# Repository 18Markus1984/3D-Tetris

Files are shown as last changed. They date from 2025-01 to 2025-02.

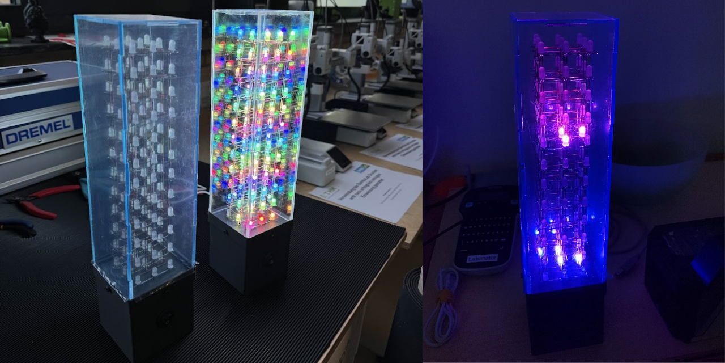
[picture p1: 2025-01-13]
picture_videos/GitHub.png

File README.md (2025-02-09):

# 3D Tetris on a 3x3x12 LED Matrix

Welcome to the 3D Tetris project! This repository documents the creation of a 3x3x12 LED matrix that enables users to play a fully functional 3D Tetris game. The project leverages an ESP32-based development board (ESPduino) with integrated web server functionality for remote control.





## Project Overview

This project was developed as part of the **"Applied Microcontroller Technology"** module and integrates hardware assembly, software programming, and web-based GUI design. Inspired by the game available at [3DTetris.de](https://3dtetris.de/), the system enables interactive gameplay through a wireless web interface.

Key features include:
- A custom-built 3x3x12 RGB LED matrix.
- ESP32 microcontroller for controlling LEDs and hosting a local web server.
- A responsive web interface for gameplay and real-time interactions.
- Open-source software written in C, HTML, CSS, and JavaScript.

---

## Features

### Hardware
- **ESPduino Controller**: Combines the ESP32 Wi-Fi chip with Arduino-compatible GPIO layout.
- **3x3x12 LED Matrix**: Comprised of 108 individually addressable PL9823 RGB LEDs.
- **Custom Housing**: 3D-printed for modularity and ease of assembly.
- **Power Supply**: Powered via USB-C with an integrated on/off switch.

### Software
- **LED Control**: Powered by the FastLED library for efficient matrix management.
- **Game Logic**: Implements Tetris gameplay mechanics including rotation, collision detection, and line clearing.
- **Web Interface**: HTML/CSS-based [GUI](./picture_videos/webserver_gui.png) hosted via an onboard web server, with multi-language support.

### Gameplay
- Control Tetrominoes (Tetris blocks) through the GUI.
- Real-time rendering of blocks on the LED matrix.
- Score tracking and high-score leaderboard.
- Adjustable levels and difficulty scaling.
- High-score table to save and display the top 10 scores.
- Difficulty selection for custom gameplay experiences.

---

## Getting Started  

### Prerequisites  

#### Assembly
- [Circuit](https://github.com/18Markus1984/3D-Tetris/wiki/Soldering-the-Circuit): The LED matrix is powered and controlled through a single GPIO pin of the ESPduino. A 5V USB-C power supply is used for both the matrix and the ESPduino.
- [LED Matrix](https://github.com/18Markus1984/3D-Tetris/wiki/Building-the-LED-Matrix): LEDs are arranged in a 3x3x12 grid and tested individually for functionality. Custom fixtures were used to ensure precision during soldering. 
- [3D printed Case](https://github.com/18Markus1984/3D-Tetris/wiki/Assembling-the-Case): The case, 3D-printed using PLA, features dedicated mounts for the ESPduino, USB ports, and optional counterweights to enhance stability.
- [How the Code Works](https://github.com/18Markus1984/3D-Tetris/wiki/How-the-Code-Works): The ESP32 Tetris game is explained using a flowchart, detailing initialization, web interface, user input processing, game logic, scoring, and game over handling.

#### Software  
- **Arduino IDE**: Download and install the [Arduino IDE](https://www.arduino.cc/en/software).  
- **ESP32 Board Manager**: Add the ESP32 board manager by following [this guide](https://docs.espressif.com/projects/arduino-esp32/en/latest/getting_started.html).  
- **Libraries**: Install the following libraries:  
  - Via Arduino IDE Library Manager:  
    - `FastLED`  
    - `WiFi`  
    - `Preferences`  
  - **ESPForm Library**:  
    - Download the library from the [ESPForm GitHub repository](https://github.com/mobizt/ESPForm).  
    - Extract the downloaded ZIP file.  
    - Copy the extracted folder into the `libraries` directory of your Arduino IDE sketchbook folder.  

### Installation  

1. **Clone the Repository**  
   Open a terminal and run the following command to clone the repository:  
   ```bash  
   git clone https://github.com/18Markus1984/3D-Tetris.git  
   ```  

2. **Open the Project in Arduino IDE**  
   Navigate to the cloned folder and open the `.ino` file in the Arduino IDE.  

3. **Configure the ESP32 Board**  
   - Go to **Tools** > **Board** and select **ESP32 Dev Module**.  
   - Enable **PSRAM** under **Tools** > **PSRAM**.  

4. **Upload the Sketch**  
   - Ensure the correct COM port is selected under **Tools** > **Port**.  
   - Click the **Upload** button to flash the code onto the ESPduino.  

5. **Connect to the ESP32's Wi-Fi Network**  
   - On your computer or mobile device, connect to the Wi-Fi network:  
     - **SSID**: `3D-Tetris`  
     - **Password**: `12345678`  

6. **Access the Web Interface**  
   - Open a web browser and navigate to:  
     - [http://192.168.4.1](http://192.168.4.1)  

You can now enjoy 3D Tetris using the interactive web interface!  

---

## How It Works

### Code Flow Chart
```mermaid
graph TD;
    Start["ESP32 starts"] --> InitWiFi["Initialize WiFi"];
    InitWiFi --> LoadWebPage["Load webpage from html.h"];
    LoadWebPage --> WaitForClient["Wait for client requests"];
    
    WaitForClient -->|Start button pressed| StartGame["Start game"];
    StartGame --> GameLoop["Game loop"];
    
    GameLoop -->|Movement input received| UpdatePosition["Update piece position"];
    UpdatePosition --> GameLoop;
    
    GameLoop -->|Rotation input received| RotatePiece["Rotate piece"];
    RotatePiece --> GameLoop;
    
    GameLoop -->|Piece falls| CheckCollision["Check collision"];
    CheckCollision -->|Collision detected| PlacePiece["Place piece"];
    PlacePiece --> CheckLines["Check for complete lines"];
    CheckLines -->|Lines found| RemoveLines["Remove lines"];
    RemoveLines --> UpdateScore["Update score"];
    UpdateScore --> GameLoop;
    
    CheckLines -->|No lines| GameLoop;
    
    GameLoop -->|Game over| GameOver["Game Over"];
    GameOver --> WaitForClient;
```

### LED Matrix
- **Construction**: LEDs are arranged in a 3x3x12 format, connected using PL9823-compatible drivers.
- **Control**: Each LED is addressed individually using a mapped index for 3D coordinates.

### Web Interface
- **Languages Supported**: English, German, French, Spanish, Italian.
- **Functions**:
  - Rotate blocks around X, Y, Z axes.
  - Shift blocks along the XY-plane.
  - Drop blocks into place.
- **Additional Features**:
  - Live preview of the next Tetromino.
  - Display of current score and level.
  - **High-Score Table**: Saves and displays the top 10 scores along with player names. Extra entries are shown but not stored persistently.
  - **Difficulty Selection**: Choose between multiple difficulty levels to adjust the gameplay experience.

---

## Results

The project met its primary objectives, showcasing:
1. A functional 3D Tetris game on a custom LED matrix.
2. An intuitive and accessible web-based control interface.
3. High scalability for future enhancements, including battery power and improved stability.

---

## Future Improvements
- Reduce input latency for smoother gameplay.
- Enhance matrix stability to minimize movement during transport.
- Add battery support for portability.
- Optimize collision detection and rotation algorithms to avoid edge-case errors.

---

## Acknowledgments

This project was developed by Marvin Heins, Markus Schmidt, and Leonard Holz-Diehl. Special thanks to the open-source community and the developers of the FastLED library.

---

## License

This project is licensed under the GNU General Public License v3.0. See the `LICENSE` file for more details.

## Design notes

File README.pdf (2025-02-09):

README.md | 2025-02-09

# 3D Tetris on a 3x3x12 LED Matrix

Welcome to the 3D Tetris project! This repository documents the creation of a 3x3x12 LED matrix that enables users to play a fully functional 3D Tetris game. The project leverages an ESP32-based development board (ESPduino) with integrated web server functionality for remote control.

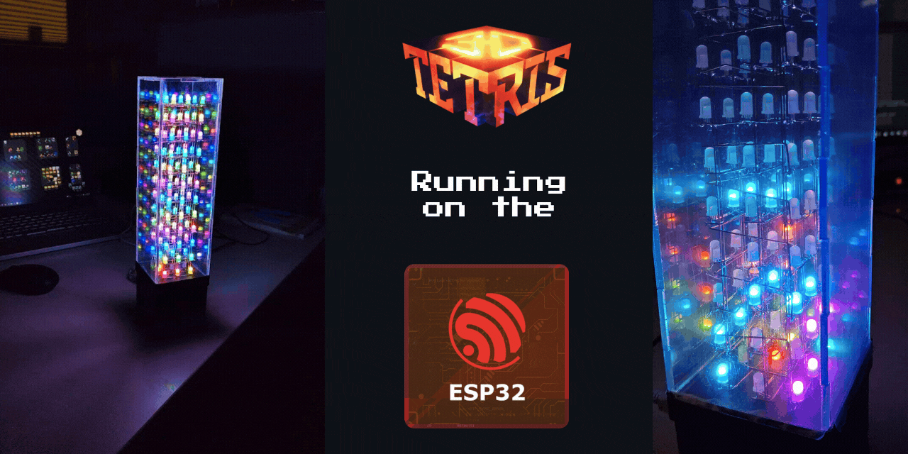
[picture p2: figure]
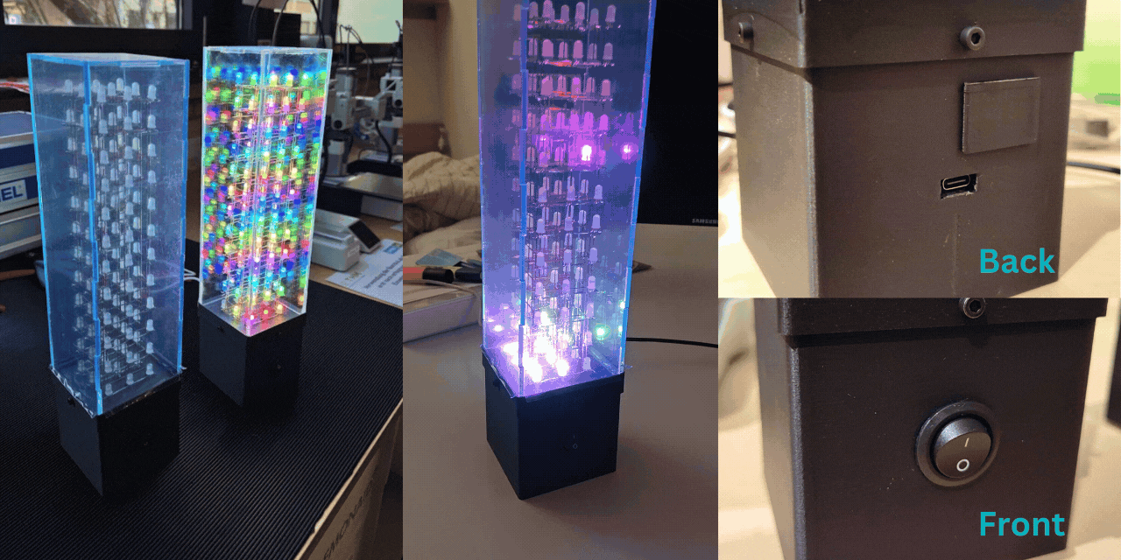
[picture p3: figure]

## Project Overview

This project was developed as part of the "Applied Microcontroller Technology" module and integrates hardware assembly, software programming, and web-based GUI design. Inspired by the game available at 3DTetris.de, the system enables interactive gameplay through a wireless web interface.

Key features include:

A custom-built 3x3x12 RGB LED matrix.
ESP32 microcontroller for controlling LEDs and hosting a local web server. A responsive web interface for gameplay and real-time interactions. Open-source software written in C, HTML, CSS, and JavaScript.

## Features

Hardware

ESPduino Controller: Combines the ESP32 Wi-Fi chip with Arduino-compatible GPIO layout. 3x3x12 LED Matrix: Comprised of 108 individually addressable PL9823 RGB LEDs.
Custom Housing: 3D-printed for modularity and ease of assembly.
Power Supply: Powered via USB-C with an integrated on/off switch.
Software

LED Control: Powered by the FastLED library for efficient matrix management.
Game Logic: Implements Tetris gameplay mechanics including rotation, collision detection, and line clearing.
Web Interface: HTML/CSS-based GUI hosted via an onboard web server, with multi-language support.
Gameplay

Control Tetrominoes (Tetris blocks) through the GUI.
Real-time rendering of blocks on the LED matrix. Score tracking and high-score leaderboard. Adjustable levels and difficulty scaling.
High-score table to save and display the top 10 scores. Difficulty selection for custom gameplay experiences.

## Getting Started

Prerequisites

Assembly

Circuit: (https://github.com/18Markus1984/3D-Tetris/wiki/Soldering-the-Circuit) The LED matrix is powered and controlled through a single GPIO pin of the ESPduino. A 5V USB-C power supply is used for both the matrix and the ESPduino.
LED Matrix: (https://github.com/18Markus1984/3D-Tetris/wiki/Building-the-LED-Matrix) LEDs are arranged in a 3x3x12 grid and tested individually for functionality. Custom fixtures were used to ensure precision during soldering.
3D printed Case: (https://github.com/18Markus1984/3D-Tetris/wiki/Assembling-the-Case) The case, 3D-printed using PLA, features dedicated mounts for the ESPduino, USB ports, and optional counterweights to enhance stability.
How the Code Works: (https://github.com/18Markus1984/3D-Tetris/wiki/Flowchart-Walkthrough:-How-the-Code-Works) The ESP32 Tetris game is explained using a flowchart, detailing initialization, web interface, user input processing, game logic, scoring, and game over handling.

Software

Arduino IDE: Download and install the Arduino IDE. (https://www.arduino.cc/en/software)
ESP32 Board Manager: Add the ESP32 board manager by following this guide. (https://docs.espressif.com/projects/arduino-esp32/en/latest/getting_started.html) Libraries: Install the following libraries:
Via Arduino IDE Library Manager:
FastLED
WiFi
Preferences
ESPForm Library:
Download the library from the ESPForm GitHub repository. (https://github.com/mobizt/ESPForm)
Extract the downloaded ZIP file.
Copy the extracted folder into the libraries directory of your Arduino IDE sketchbook folder.
Installation
1. Clone the Repository
Open a terminal and run the following command to clone the repository:
2. Open the Project in Arduino IDE
Navigate to the cloned folder and open the .ino file in the Arduino IDE.
3. Configure the ESP32 Board

Go to Tools > Board and select ESP32 Dev Module.
Enable PSRAM under Tools > PSRAM.
4. Upload the Sketch

Ensure the correct COM port is selected under Tools > Port. Click the Upload button to flash the code onto the ESPduino.

5. Connect to the ESP32's Wi-Fi Network

On your computer or mobile device, connect to the Wi-Fi network: SSID: 3D-Tetris
Password: 12345678
6. Access the Web Interface

Open a web browser and navigate to: http://192.168.4.1

You can now enjoy 3D Tetris using the interactive web interface!

## How It Works

Code Flow Chart

graph TD;
Start["ESP32 starts"] --> InitWiFi["Initialize WiFi"];
InitWiFi --> LoadWebPage["Load webpage from html.h"]; LoadWebPage --> WaitForClient["Wait for client requests"];

WaitForClient -->|Start button pressed| StartGame["Start game"];
StartGame --> GameLoop["Game loop"];

GameLoop -->|Movement input received| UpdatePosition["Update piece position"]; UpdatePosition --> GameLoop;

GameLoop -->|Rotation input received| RotatePiece["Rotate piece"]; RotatePiece --> GameLoop;

GameLoop -->|Piece falls| CheckCollision["Check collision"]; CheckCollision -->|Collision detected| PlacePiece["Place piece"]; PlacePiece --> CheckLines["Check for complete lines"]; CheckLines -->|Lines found| RemoveLines["Remove lines"]; RemoveLines --> UpdateScore["Update score"];
UpdateScore --> GameLoop;

CheckLines -->|No lines| GameLoop;

GameLoop -->|Game over| GameOver["Game Over"]; GameOver --> WaitForClient;

LED Matrix

Construction: LEDs are arranged in a 3x3x12 format, connected using PL9823-compatible drivers. Control: Each LED is addressed individually using a mapped index for 3D coordinates.
Web Interface

Languages Supported: English, German, French, Spanish, Italian.
Functions:
Rotate blocks around X, Y, Z axes.
Shift blocks along the XY-plane.
Drop blocks into place.
Additional Features:
Live preview of the next Tetromino.
Display of current score and level.
High-Score Table: Saves and displays the top 10 scores along with player names. Extra entries are shown but not stored persistently.
Difficulty Selection: Choose between multiple difficulty levels to adjust the gameplay experience.

## Results

The project met its primary objectives, showcasing:

1. A functional 3D Tetris game on a custom LED matrix.
2. An intuitive and accessible web-based control interface.
3. High scalability for future enhancements, including battery power and improved stability.

## Future Improvements

Reduce input latency for smoother gameplay.
Enhance matrix stability to minimize movement during transport.
Add battery support for portability.
Optimize collision detection and rotation algorithms to avoid edge-case errors.

## Acknowledgments

This project was developed by Marvin Heins, Markus Schmidt, and Leonard Holz-Diehl. Special thanks to the open-source community and the developers of the FastLED library.

## License

This project is licensed under the GNU General Public License v3.0. See the LICENSE file for more details.

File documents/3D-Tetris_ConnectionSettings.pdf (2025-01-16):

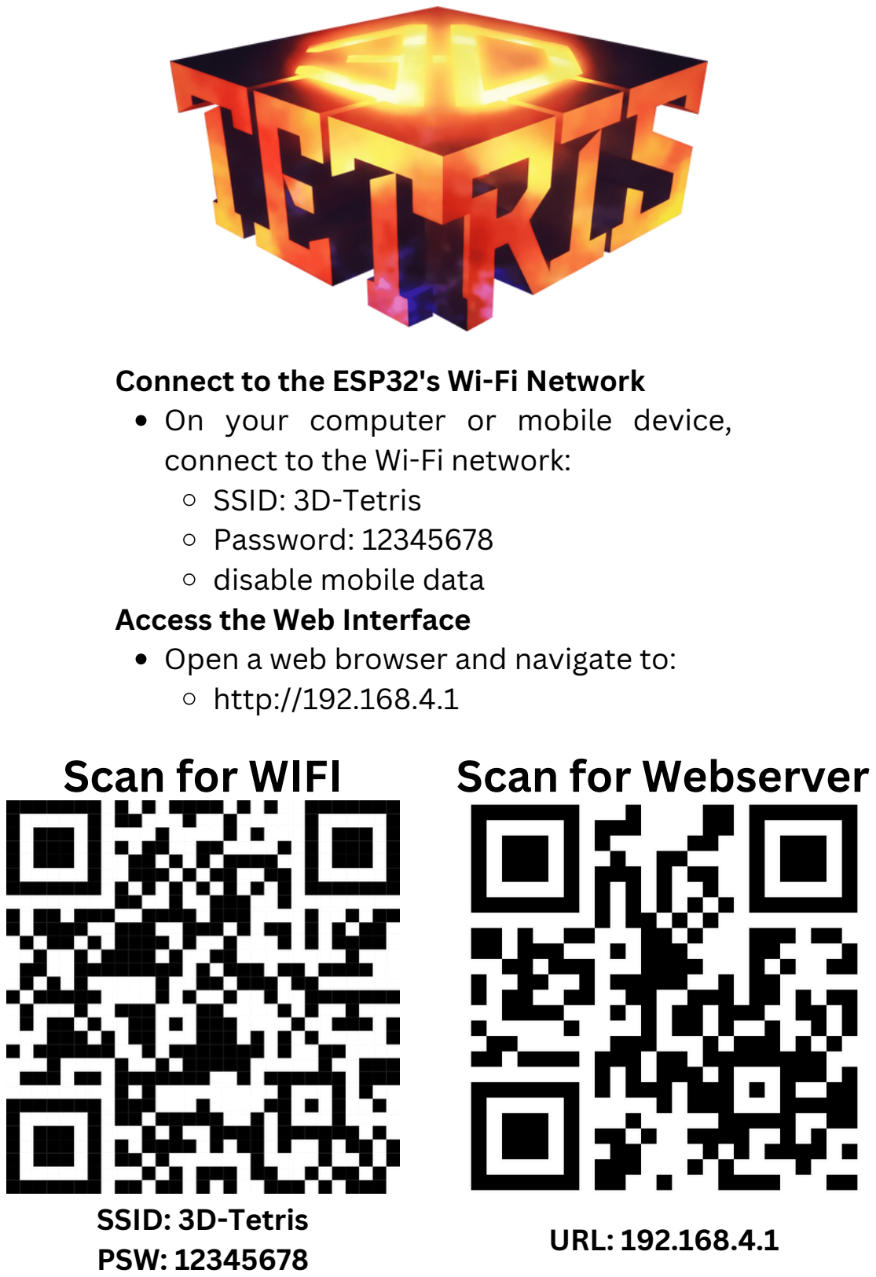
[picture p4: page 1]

## Scan for WIFI Scan for Webserver

Connect to the ESP32's Wi-Fi Network
On your computer or mobile device, connect to the Wi-Fi network:
SSID: 3D-Tetris
Password: 12345678
disable mobile data
Access the Web Interface
Open a web browser and navigate to: http://192.168.4.1

SSID: 3D-Tetris
PSW: 12345678

URL: 192.168.4.1

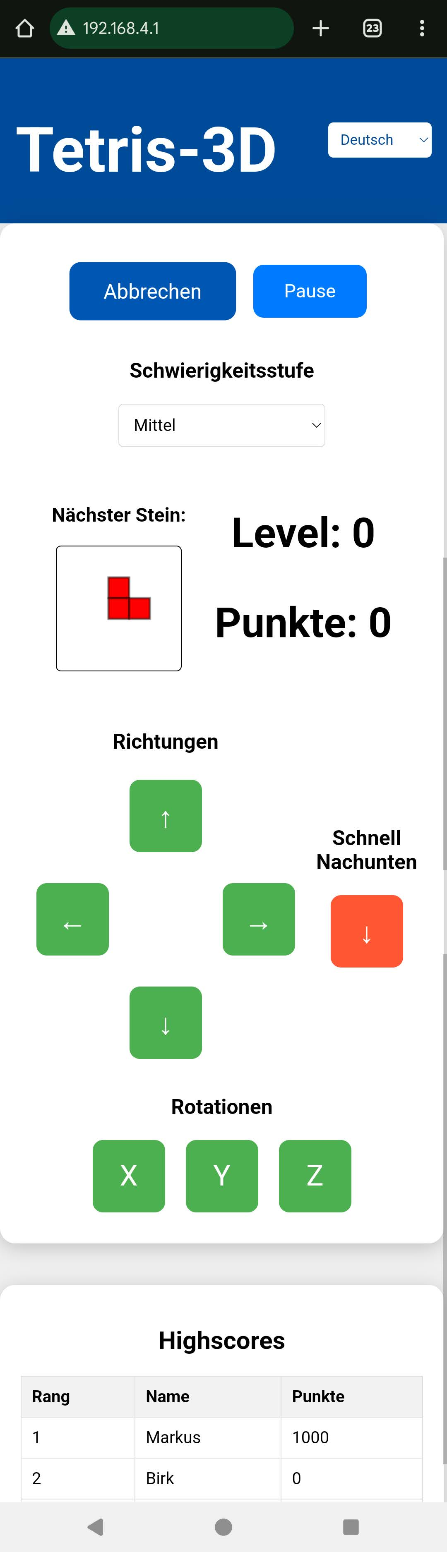
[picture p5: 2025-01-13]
picture_videos/webserver_gui.png

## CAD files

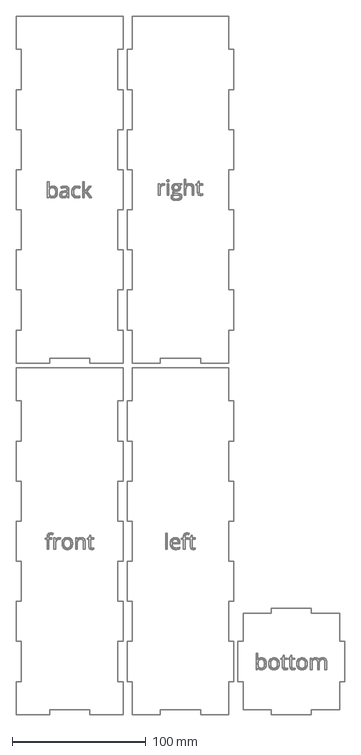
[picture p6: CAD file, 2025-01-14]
3D-Model/Laser_Milling/plexiglas_cutting.dxf
246.0 x 523.0 mm

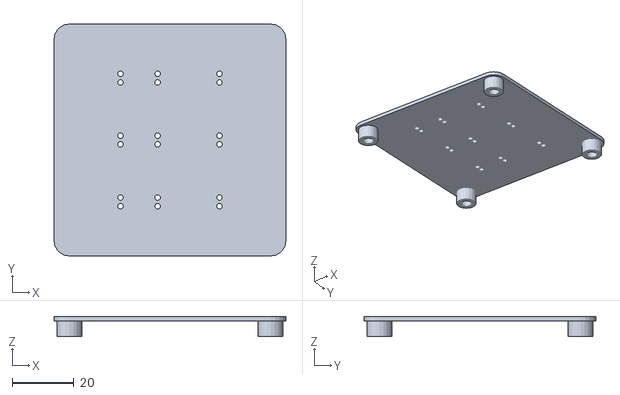
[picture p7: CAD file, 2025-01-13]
3D-Model/STLs/case/LED_Cube_Halter_V2.stl
75.0 x 75.0 x 6.50

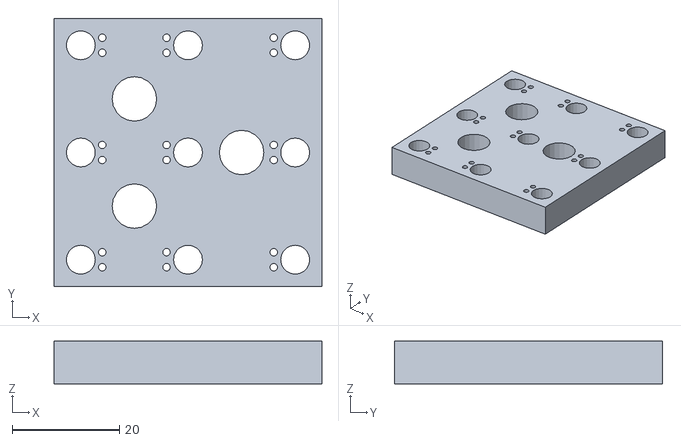
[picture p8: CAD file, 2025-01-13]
3D-Model/STLs/parts_to_solder_matrix/Guide_LED_Cube_V5.stl
50.0 x 50.0 x 8.00

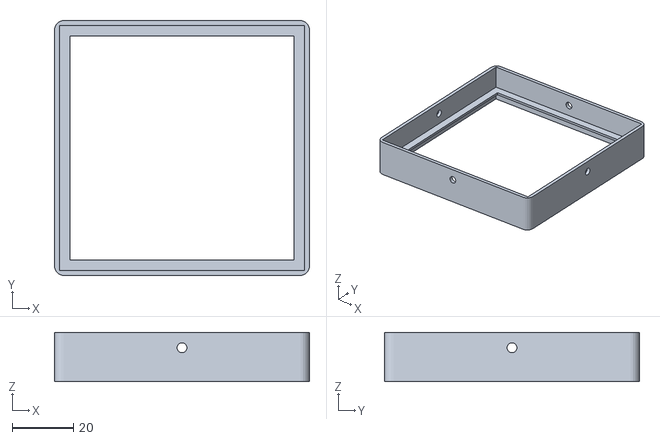
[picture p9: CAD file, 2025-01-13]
3D-Model/STLs/case/Aufsatz_Plexi_Schraube.stl
83.0 x 83.0 x 16.0

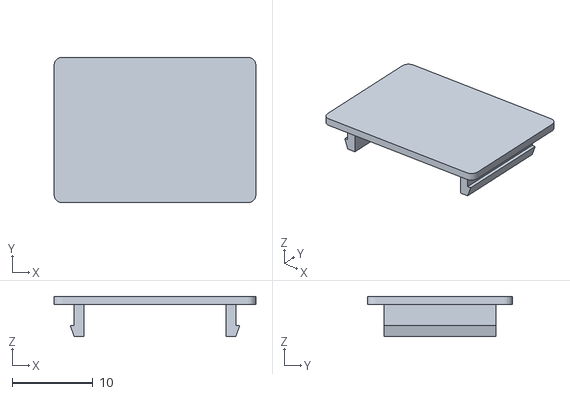
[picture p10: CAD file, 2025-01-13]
3D-Model/STLs/case/Abdeckung05.stl
25.0 x 18.0 x 5.00

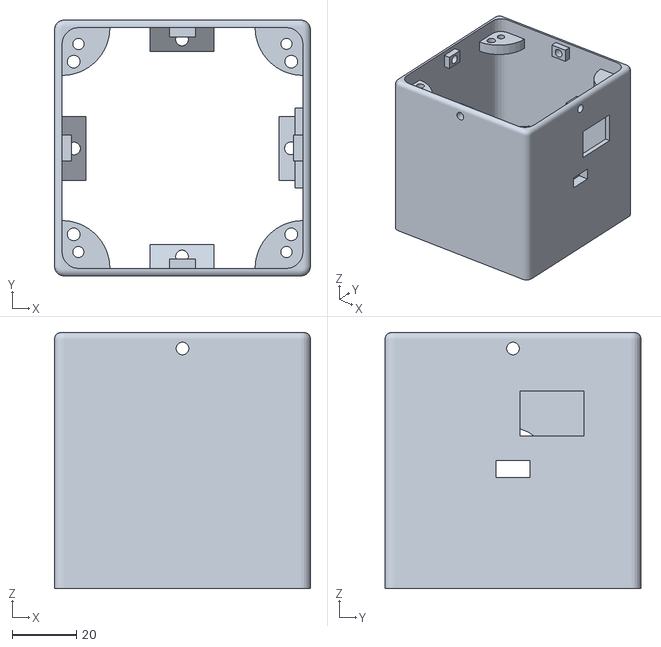
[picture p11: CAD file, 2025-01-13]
3D-Model/STLs/case/Gehauese_LED_Cube_plex.stl
80.0 x 80.0 x 80.0

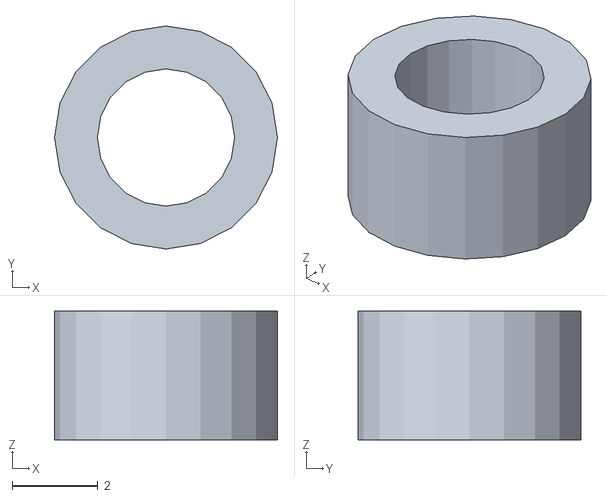
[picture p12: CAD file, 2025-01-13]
3D-Model/STLs/case/Spacer.stl
5.20 x 5.20 x 3.00

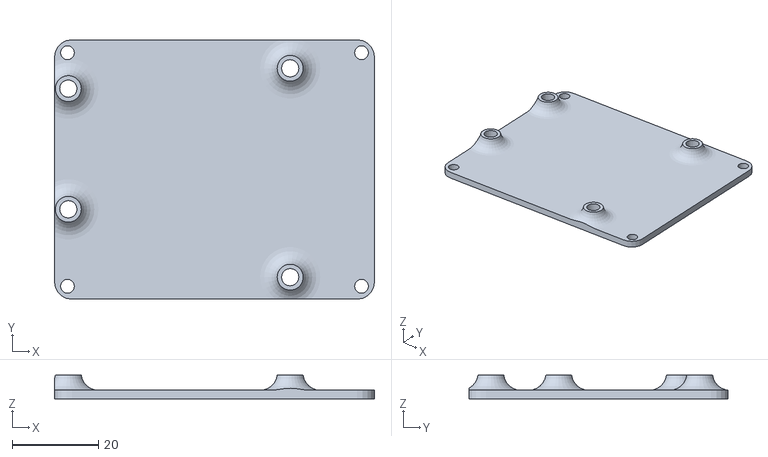
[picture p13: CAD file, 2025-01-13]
3D-Model/STLs/case/Halter_ESPduino.stl
74.0 x 60.0 x 5.50

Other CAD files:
3D-Model/NX/Abdeckung.prt
3D-Model/NX/Aufsatz_Plexi.prt
3D-Model/NX/Baugruppe_LED_Cube.prt
3D-Model/NX/Gehauese_LED_Cube.prt
3D-Model/NX/Halter_ESPduino.prt
3D-Model/NX/LED_Cube_Halter.prt
3D-Model/NX/Spacer.prt

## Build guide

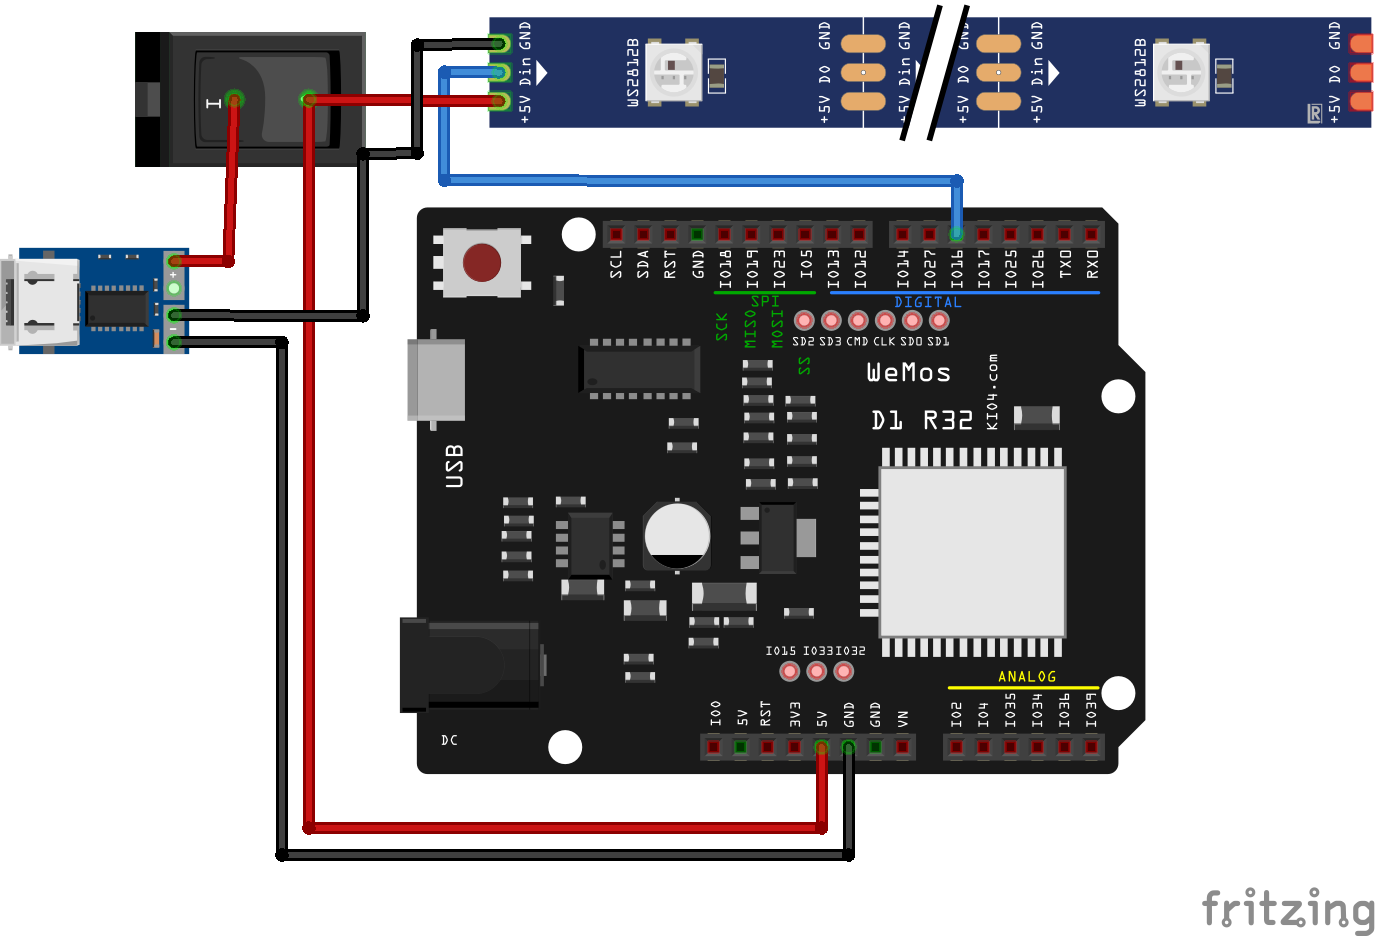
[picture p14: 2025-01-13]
picture_videos/wiring_diagram.png

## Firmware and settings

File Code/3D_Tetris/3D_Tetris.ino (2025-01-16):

//libraries used 
#include <FastLED.h>
#include <WiFi.h> //ESP32
#include <ESPForm.h>
#include <Preferences.h>

//Split into different files for better legibility 
#include "html.h"
String configFileName = "/wifi.json";

//The Wifi-credentials for logging in 
String apSSID = "3D-Tetris";
String apPSW = "12345678";
unsigned long serverTimeout = 2 * 60 * 1000;


const int X_DIM = 3;  // dimensin in X-direction
const int Y_DIM = 3;  // dimension in Y-direction
const int Z_DIM = 12;  // Adjustable dimension in Z-direction (testet for 10 and 12)

//LED Settings
#define LED_PIN 16
#define NUM_LEDS 108     // Number of LEDs
#define MAX_X 3          // Dimension X (3 layers)
#define MAX_Y 3          // Dimension Y (3 lines)
#define MAX_Z 12         // Dimension Z (12 columns)

//Idle Animation
#define TEMPERATURE_1 Tungsten100W
#define TEMPERATURE_2 OvercastSky
#define BRIGHTNESS  80

// How many seconds to show each temperature before switching
#define DISPLAYTIME 20

// How many seconds to show black between switches
#define BLACKTIME   1

// FastLED-Array  
CRGB leds[NUM_LEDS];

//Eeproom-adresses
Preferences preferences;

//Storage for the 3D-Matrix digital twin (with the variable dimensions)
int matrix[X_DIM][Y_DIM][Z_DIM]; 

//Color Options
byte color[25][3] = {{255,0,0},{255,64,0},{255,128,0},{255,191,0},{255,255,0},{191,255,0},{128,255,0},{64,255,0},{0,255,0},{0,255,64},{0,255,128},{0,255,191},{0,255,255},{0,191,255},
{0,128,255},{0,64,255},{0,0,255},{64,0,255},{128,0,255},{191,0,255},{255,0,255},{255,0,191},{255,0,128},{255,0,64},{255,0,0}};  //Array with the different color-values would be better to do this with a function
int row = 0;  //variable, that shows which color is selected 

//Struct for Tetrominos with extended points
struct Tetromino {
    int points[5][3];  // The 5 points in the format of {x, y, z}; non used values are set to -3
    int xPos;         // X-Position of the  Tetrominos
    int yPos;         // Y-Position of the Tetrominos
    int colorIndex;    // Color of the Tetrominos (Index in color-Array)
};

// Tetrominos with 5 points (non used points set to -3)
Tetromino tetrominos[] = {
    //Easy mode:
    // Point-Tetromino - 0
    {
        {{1, 1, 1}, {-3, -3, -3}, {-3, -3, -3}, {-3, -3, -3}, {-3, -3, -3}}, 
        0,0,0 // Color
    },
    // I-Tetromino - 1
    {
        {{0, 1, 1}, {1, 1, 1}, {2, 1, 1}, {-3, -3, -3}, {-3, -3, -3}},
        0,0,0  // Color
    },
    // Small-I-Tetromino - 2
    {
        {{0, 1, 1}, {1, 1, 1}, {-3, -3, -3}, {-3, -3, -3}, {-3, -3, -3}}, 
        0,0,0  // Color
    },
    //middle:
    // L-Tetromino - 3
    {
        {{1, 0, 1}, {1, 1, 1}, {1, 2, 1}, {2, 2, 1}, {-3, -3, -3}}, 
        0,0,0  // Color
    },
    // T-Tetromino - 4
    {
        {{1, 0, 1}, {0, 1, 1}, {1, 1, 1}, {2, 1, 1}, {-3, -3, -3}}, 
        0,0,0  // color
    },
    // S-Tetromino - 5
    {
        {{0, 1, 1}, {1, 0, 1}, {1, 1, 1}, {2, 0, 1}, {-3, -3, -3}}, 
        0,0,0  // Color
    },
    // o-Tetromino - 6
    {
        {{0, 0, 1}, {0, 1, 1}, {1, 0, 1}, {1, 1, 1}, {-3, -3, -3}}, 
        0,0,0  // Color
    },
    // Small-L-Tetromino - 7
    {
        {{0, 1, 1}, {1, 1, 1}, {1, 2, 1}, {-3, -3, -3},{-3, -3, -3}}, 
        0,0,0  // color
    },
    //Expert:
    // Star-Tetromino - 8
    {
        {{0, 1, 1}, {1, 0, 1}, {1, 1, 1},  {2, 1, 1}, {1, 2, 1}}, 
        0,0,0  // Color
    },
    // Big-S-Tetromino - 9
    {
        {{0, 0, 1}, {0, 1, 1}, {1, 1, 1},  {2, 1, 1}, {2, 2, 1}}, 
        0,0,0  // Color
    },
    // Big-T-Tetromino - 10
    {
        {{0, 1, 1}, {1, 1, 1}, {2, 0, 1}, {2, 1, 1}, {2, 2, 1}}, 
        0,0,0  // Color
    },
    // Handy-Tetromino - 11
    {
        {{0, 1, 1}, {1, 1, 1}, {1, 0, 1},{2, 1, 1}, {2, 0, 1}}, 
        0,0,0  // Color
    },
    // Big-U-Tetromino - 12
    {
        {{0, 0, 1}, {0, 1, 1}, {1, 1, 1}, {2, 1, 1}, {2, 0, 1}}, 
        0,0,0  // Color
    },
    // Big-L-Tetromino - 13
    {
        {{0, 0, 1}, {0, 1, 1}, {0, 2, 1}, {1, 2, 1}, {2, 2, 1}}, 
        0,0,0  // Color
    },
    // L with dot -Tetromino - 14
    {
        {{1, 0, 1}, {1, 1, 1}, {1, 2, 1}, {2, 2, 1}, {0, 1, 1}}, 
        0,0,0  // Color
    },
    // stair-Tetromino - 15
    {
        {{0, 0, 1}, {0, 1, 1}, {1, 1, 1}, {1, 2, 1}, {2, 2, 1}}, 
        0,0,0  // Color
    },

    //3D Terominos:
    // 3*1 with corner -Tetromino - 16
    {
        {{0, 1, 1}, {1, 1, 1}, {2, 1, 1}, {0, 0, 0}, {1, 0, 0}}, 
        0,0,0  // Farbe
    },
    // L with dot -Tetromino - 17
    {
        {{1, 0, 1}, {1, 1, 1}, {1, 2, 1}, {2, 2, 1}, {1, 1, 0}}, 
        0,0,0  // Farbe
    },
    // T with dot -Tetromino - 18
    {
        {{1, 0, 1}, {0, 1, 1}, {1, 1, 1}, {2, 1, 1}, {1, 1, 0}}, 
        0,0,0  // Farbe
    },
    // S with dot -Tetromino - 20
    {
        {{0, 1, 1}, {1, 0, 1}, {1, 1, 1}, {2, 0, 1}, {1, 1, 0}}, 
        0,0,0  // Farbe
    },
    // o with dot -Tetromino - 21
    {
        {{0, 0, 1}, {0, 1, 1}, {1, 0, 1}, {1, 1, 1}, {1, 1, 0}}, 
        0,0,0  // Farbe
    },
    // Small-KoordinatenSystem-Tetromino - 22
    {
        {{0, 1, 1}, {1, 1, 1}, {1, 2, 1},{1, 1, 0}, {-3, -3, -3}}, 
        0,0,0  // Farbe
    }
};

//Tetris realted Variables:
Tetromino currentTetromino;   // The active Tetromino
int nextTetrominoIndex = 0;   // The next Tetromino block as index of the Arrays
int currentZ = 0;             // Latest Z-Position of the falling Tetrominos
bool gameRunning = false;     // Variable to check if the game is running right now 
int gameDelay = 1000;         // variable to track the time of the now running action. Examples: block is falling or collision of blocks
int score = 0;                // variable to store the score of the running game
int levelScore = 0;           // variable that shows the level in which the user is. the level inceases every 10th layer they cleared
String playerData = "";       // string which buffers the highscore data
int difficulty = 0;           // variable to set the difficulty of the game
bool changeScore = false;     // toggle to signal that the new score has to be saved
int ElementCounter = 0;
ESPFormClass::HTMLElementItem ElementTrigger;   // set a Element for the Element press/or value change interrupts
ESPFormClass::HTMLElementItem PreviousElementTrigger; 
String elementButton = "";

//regular Arduino functions
void setup();
void loop();

//3D-Tetris related functions
void idleAnimtation();                                                                 // function that shows an animation while no game is running
void gameOver();                                                                       // function to reset all values after gameOver
void saveData(String highscoreString);                                                 // function that saves the Highscore values on the Eproom of the Esp
void splitHighscores(String input, String names[], int scores[], int maxEntries);      // function to split the input string into different HighScore values
void clearMatrix();                                                                    // funciton to clear the matrix
int XYZ_to_index(int x, int y, int z);                                                 // function to calculate the LED-Index based on 3D-coordinates
void updateLEDs();                                                                     // function to refresh the LEDs based on the matrix
void renderTetromino(Tetromino &tetromino, int z, bool clear);                         // function to draw the position of the tetromino in the matrix temporary
void placeTetromino(Tetromino &tetromino, int z);                                      // function to put the tetromino in the matrix
bool moveTetrominoDown(Tetromino &tetromino);                                          // funciton to move the tetromino down
bool canPlaceTetromino(Tetromino &tetromino, int z);                                   // function to check the placement of the tetromino (collison check)
void updateAndDisplayMatrix();                                                         // function to display the game matrix in the serial monitor 
void spawnNewTetromino();                                                              // function to chose a random new Tetromino
int spawnRelativeToDiff();                                                             // function that returns a random new Tetromino relative to the selected difficulti
void clearFullLevelAndShiftDown(int level);                                            // function that removes the layer and shifts every upper layer on layer lower
void checkFullLevel();                                                                 // function that checkes every layer if it is filled with blocks

//3D-Tetris movment and rotation related functions
void moveTetromino(Tetromino &tetromino, int dx, int dy, int dz);   // General movement function that moves Tetromenio in x, y or z direction depending on the input 
void fallDown(Tetromino &tetromino);                                // function that lets the Tetromino fall down until it finds a collision with a block or the ground
void rotateTetromino(Tetromino &tetromino, char axis);              // General rotation function, which is responsible for rotation in every individual funciton
bool AdjustPosition(Tetromino &tetromino, int &currentZ);           // function to find a postion if the Tetromino rotates out of the gameMatrix

//wifi and webserver realted functions
bool startWiFi();                                                         //starts the Wifi protocol
void setupESPForm();                                                      //Initialised all the EventListener for the comminication between Esp and HTML
void formElementEventCallback(ESPFormClass::HTMLElementItem element);     //function that gets called if any of the EventListener get triggered. Used to get the different button presses and value changes
void checkForGameControllElements(ESPFormClass::HTMLElementItem element); //function that calls all calls the differnt functions for every button
void serverTimeoutCallback();                                             //If server timeout (no client connected within specific time)


void setup() {
  Serial.begin(115200);

  WiFi.softAPdisconnect(true);
  WiFi.disconnect(true);
  WiFi.persistent(false);

  if (!startWiFi()) {
    setupESPForm();
    Serial.println("MAIN:  Start server");
    ESPForm.startServer();
  }
  
  FastLED.addLeds<WS2812, LED_PIN, GRB>(leds, NUM_LEDS);

  preferences.begin("myScore", false);
  playerData = preferences.getString("score");
  Serial.println(playerData);
  clearMatrix();        // initiate the matrix
  updateLEDs();
}

void loop() {
  if(ESPForm.getClientCount() > 0) {
    ESPFormClass::HTMLElementItem element = ESPForm.getElementEventConfigItem("gameScores");
    String pufferplayer = element.value; 
    if(pufferplayer == "" || pufferplayer == "null" && playerData != ""){
      ESPForm.setElementContent("gameScores", playerData);
    }
  }
  // Show the matrix in the serial monitor (for debugging)
  //updateAndDisplayMatrix();
  if(gameRunning){
    static unsigned long lastUpdateTime = 0; 
    unsigned long currentTime = millis();
  
    // Check if gameDelay time have passed
    if (currentTime - lastUpdateTime >= gameDelay) {
      lastUpdateTime = currentTime;
      // Try to move the Tetromino down
      if (!moveTetrominoDown(currentTetromino)) {
        // Movement failed -> Spawn new Tetromino
        spawnNewTetromino();
      }
    }
  }
  else {
    idleAnimtation();
  }
  Serial.println(elementButton);
  if(elementButton != "") {
    checkForGameControllElements(elementButton);
    elementButton = "";
  }
}

// function that shows an animation while no game is running
void idleAnimtation(){
  // draw a generic, no-name rainbow
  static uint8_t starthue = 0;
  fill_rainbow( leds + 5, NUM_LEDS - 5, --starthue, 20);

  // Choose which 'color temperature' profile to enable.
  uint8_t secs = (millis() / 1000) % (DISPLAYTIME * 2);
  if( secs < DISPLAYTIME) {
    FastLED.setTemperature( TEMPERATURE_1 ); // first temperature
    leds[0] = TEMPERATURE_1; // show indicator pixel
  } else {
    FastLED.setTemperature( TEMPERATURE_2 ); // second temperature
    leds[0] = TEMPERATURE_2; // show indicator pixel
  }

  // Black out the LEDs for a few seconds between color changes
  // to let the eyes and brains adjust
  if( (secs % DISPLAYTIME) < BLACKTIME) {
    memset8( leds, 0, NUM_LEDS * sizeof(CRGB));
  }
  FastLED.show();
  FastLED.delay(8);
}

// function to reset all values after gameOver
void gameOver(){
  gameRunning = false;
  Serial.println("Game Over!");
  ESPForm.setElementContent("gameOverInput", "GameOver");
  clearMatrix();
  updateLEDs();
}

// function that saves the Highscore values on the Eproom of the Esp
void saveData(String highscoreString){
  Serial.println("SaveData");
  Serial.println(highscoreString);
  int maxEntries = 10; // Max amout of stored entries
  int count = 0;
  String names[maxEntries];
  int scores[maxEntries];
  
  //Call the function
  splitHighscores(highscoreString, names, scores, maxEntries);
  String scoreData = "";
  for (int i = 0; i < maxEntries; i++) {
    if (names[i] != "") { // check if the name is valid
      Serial.print("Name: ");
      Serial.print(names[i]);
      Serial.print(", Score: ");
      Serial.println(scores[i]);
      scoreData+= names[i]+","+scores[i]+";";
    }
  }
  preferences.putString("score",scoreData);
  playerData = scoreData;
}

// function to split the input string into different HighScore values
void splitHighscores(String input, String names[], int scores[], int maxEntries) {
  int entryIndex = 0;
  while (input.length() > 0 && entryIndex < maxEntries) {
    int delimiterPos = input.indexOf(';');
    String entry;
    if (delimiterPos != -1) {
      entry = input.substring(0, delimiterPos);
      input = input.substring(delimiterPos + 1);
    } else {
      entry = input;
      input = "";
    }

    int commaPos = entry.indexOf(',');
    if (commaPos != -1) {
      names[entryIndex] = entry.substring(0, commaPos);
      scores[entryIndex] = entry.substring(commaPos + 1).toInt();
      entryIndex++;
    }
  }
}

// funciton to clear the matrix
void clearMatrix() {
  Serial.println("Clear-Matrix");
  for (int z = 0; z < Z_DIM; z++) {
    for (int y = 0; y < Y_DIM; y++) {
      for (int x = 0; x < X_DIM; x++) {
        matrix[x][y][z] = 0; // Initiate matrix with zero
      }
    }
  }
}

// function to calculate the LED-Index based on 3D-coordinates
int XYZ_to_index(int x, int y, int z) {
  int reverseZ = MAX_Z - 1 - z; // invert z-direction(from top to bottom)
  return (reverseZ * MAX_X * MAX_Y) + (y * MAX_X) + x;
}

// function to refresh the LEDs based on the matrix
void updateLEDs() {
  for (int x = 0; x < MAX_X; x++) {
    for (int y = 0; y < MAX_Y; y++) {
      for (int z = 0; z < MAX_Z; z++) {
        int index = XYZ_to_index(x, y, z);
        if (index < NUM_LEDS) { // check: Index in range
          if (matrix[x][y][z] > 0 && matrix[x][y][z] <= 25) {
            leds[index].setRGB(color[matrix[x][y][z]][0],color[matrix[x][y][z]][1],color[matrix[x][y][z]][2]); // Stone active: colored
          } else {
            leds[index] = CRGB::Black; // stone deactivated: LED off
          }
        }
      }
    }
  }
  FastLED.show();
}

// function to draw the position of the tetromino in the matrix temporary
void renderTetromino(Tetromino &tetromino, int z, bool clear = false) {
    for (int i = 0; i < 5; i++) {
        //Check if the point is vaild (ignore -3)
        if (tetromino.points[i][0] != -3) {
            int nx = tetromino.xPos + tetromino.points[i][0];
            int ny = tetromino.yPos + tetromino.points[i][1];
            int nz = z + tetromino.points[i][2];

            //Check if the point is in the boundaries of the matrix 
            if (nx >= 0 && nx < X_DIM && ny >= 0 && ny < Y_DIM && nz >= 0 && nz < Z_DIM) {
                matrix[nx][ny][nz] = clear ? 0 : tetromino.colorIndex;
            }
        }
    }
}

// function to put the tetromino in the matrix
void placeTetromino(Tetromino &tetromino, int z) {
    for (int i = 0; i < 5; i++) {
        //Check if the point is vaild (ignore -3)
        if (tetromino.points[i][0] != -3) {
            int nx = tetromino.xPos + tetromino.points[i][0];
            int ny = tetromino.yPos + tetromino.points[i][1];
            int nz = z + tetromino.points[i][2];

            //Set the point in the matrix if it is valid
            if (nx >= 0 && nx < X_DIM && ny >= 0 && ny < Y_DIM && nz >= 0 && nz < Z_DIM) { 
                matrix[nx][ny][nz] = tetromino.colorIndex;
            }
        }
    }
    // check and delete the complet layer 
    checkFullLevel();
}

//funciton to move the tetromino down
bool moveTetrominoDown(Tetromino &tetromino) {
    // Delete the old position in the current layer (currentZ)
    renderTetromino(tetromino, currentZ-1, true);
    renderTetromino(tetromino, currentZ, true);

    //Check if the tetrominocan be placed in the next layer
    if (canPlaceTetromino(tetromino, currentZ + 1)) {
        //Go down one layer
        currentZ++;
        // Draw the tetromino in the new z-layer
        renderTetromino(tetromino, currentZ);
        updateLEDs();
        return true;
    } else {
        // Place it if no more movment is possible
        Serial.println("Collision detected - Placement of block.");
        placeTetromino(tetromino, currentZ);
        return false;
    }
}

//Function to check the placement of the tetromino (collison check)
bool canPlaceTetromino(Tetromino &tetromino, int z) {
    for (int i = 0; i < 5; i++) {
        // Check if the point is valid (ignore -3)
        if (tetromino.points[i][0] != -3) {
            int nx = tetromino.xPos + tetromino.points[i][0];
            int ny = tetromino.yPos + tetromino.points[i][1];
            int nz = z + tetromino.points[i][2];

            // Debugging-output
            Serial.print("Check block of: (");
            Serial.print(nx);
            Serial.print(", ");
            Serial.print(ny);
            Serial.print(", ");
            Serial.print(nz);
            Serial.println(")");

            //Check if the position is outside of the matrix or collides
            if (nx < 0 || nx >= X_DIM || ny < 0 || ny >= Y_DIM || nz < 0 || nz >= Z_DIM || matrix[nx][ny][nz] != 0) {
                Serial.println("Block outside the matrix boundaries!");
                return false; // Collison detected
            }
        }
    }
    return true; // No collison, placment is empty
}

// Method to display matrix
void updateAndDisplayMatrix() {
  Serial.println("Current state of the 3D-Matrix:");
  for (int z = 0; z < Z_DIM; z++) {
    Serial.print("Layer ");
    Serial.print(z);
    Serial.println(":");
    for (int y = 0; y < Y_DIM; y++) {
      for (int x = 0; x < X_DIM; x++) {
        Serial.print(matrix[x][y][z]);
        Serial.print("\t");
      }
      Serial.println(); // New line for the next row
    }
    Serial.println(); // Blank space between the layers
  }
}

// function to chose a random new Tetromino
void spawnNewTetromino() {
  currentZ = -1; // Start in the top most layer
  Serial.print("Difficulty:");
  Serial.println(difficulty);
  currentTetromino = tetrominos[nextTetrominoIndex];
  nextTetrominoIndex = spawnRelativeToDiff();
  if(nextTetrominoIndex > 15) {
    ESPForm.setElementContent("hidden-piece-input", "16");
  }
  else{
    ESPForm.setElementContent("hidden-piece-input", String(nextTetrominoIndex));
  }

  currentTetromino.xPos = 0;                  // middle in X
  currentTetromino.yPos = 0;                  // middle in Y
  currentTetromino.colorIndex = random(1, 26);

   if (!canPlaceTetromino(currentTetromino, currentZ)) {
    renderTetromino(currentTetromino, 0);
    updateLEDs();
    gameOver();
    return;
  }
  renderTetromino(currentTetromino, currentZ);
  updateLEDs();
}

// function that returns a random new Tetromino relative to the selected difficulti
int spawnRelativeToDiff(){
  int i = 0;
  switch(difficulty){ 
    case 0:
      i = random(0, 3); // Random Tetromino difficulti easy
      break;
    case 1:
      i = random(0, 8); // Random Tetromino difficulti middel
      break;
    case 2:
      i = random(3, 13); // Random Tetromino difficulti hard
      break;
    case 3:
      i = random(3, 16); // Random Tetromino difficulti experte
      break;
    case 4:
      i = random(8, 22); // Random Tetromino difficulti impossible
      currentZ=1;
      break;
    }
    return i;
}

// function that removes the layer and shifts every upper layer on layer lower
void clearFullLevelAndShiftDown(int level) {

  // Delete the layer (set all blocks to zero)
  for (int y = 0; y < Y_DIM; y++) {
    for (int x = 0; x < X_DIM; x++) {
      matrix[x][y][level] = 0;
    }
  }

  // Shift all blocks above the deleted layer down
  for (int z = level; z > 0; z--) {
    for (int y = 0; y < Y_DIM; y++) {
      for (int x = 0; x < X_DIM; x++) {
        matrix[x][y][z] = matrix[x][y][z - 1];
      }
    }
  }

  //Set the top most layer to 0
  for (int y = 0; y < Y_DIM; y++) {
    for (int x = 0; x < X_DIM; x++) {
      matrix[x][y][0] = 0;
    }
  }
  //LED-refresh after changment in the matrix
  updateLEDs();
}
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

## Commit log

2025-01-13 Initial upload of most of the files
    [Abdeckung.prt, Abdeckung05.stl, Aufsatz_Plexi.prt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]
2025-01-13 Adding Images/Gif to have a better look
    [Abdeckung05.stl, Aufsatz_Plexi_Schraube.stl, Gehauese_LED_Cube_plex.stl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]
2025-01-14 Reworked the interupt handeling for button inputs to get a smoother and reliable play experience.
    [3D_Tetris.ino]
2025-01-14 Plexiglas manufacturing files
    [plexiglas_cutting.dxf]
2025-01-16 Better way to check the button press
2025-01-19 Update html.h
    Changed the german label for the drop button
